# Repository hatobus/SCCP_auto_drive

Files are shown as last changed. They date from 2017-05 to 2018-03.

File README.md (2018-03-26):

# SCCP_auto_drive

I want to Shishi 



## 最初に

これは会津大学課題プロジェクト「自動車の自動運転」についてのレポジトリとなります．

### 使うもの

今回使用するものは主にamazonや秋月電子で購入できるものを軸に使用しています．

- モータードライバ DRV8830 
    秋月などで購入することができます．表面実装済みですのである程度使いやすいことが特徴です．I2Cで動かすのでそれなりに知識が必要ですが慣れてしまえば
    簡単に動かすことができます．二つ使用するのでどちらかのアドレスを変更する作業をする必要があります．
    [購入](http://akizukidenshi.com/catalog/g/gK-06489/)
    [データシート](http://akizukidenshi.com/download/ds/akizuki/AE-MOTOR8830_manual.pdf)
    
 - ~~測距モジュール HC-SR40
    Amazonで購入，超音波型です．安いのが特徴で6個程搭載しています．これはGPIOで動くのでI2Cよりは操作がしやすいと思います．~~
    [購入](http://amzn.asia/jd95G4C)
    [データシート](http://akizukidenshi.com/download/ds/sainsmar/hc-sr04_ultrasonic_module_user_guidejohn_b.pdf)
	
 - 測距モジュール LV-EZ1
 	HC-SR40を使用すると，精度が出ず，値がバラバラになる．そのため，同じ超音波を使って測距するLV-EZ1を使用した．PWM制御ができ，GPIOピンを一つしか使用しないのである程度は使いやすい．
	[購入](https://www.switch-science.com/catalog/139/)
	[データシート](http://maxbotix.com/documents/LV-MaxSonar-EZ_Datasheet.pdf)

 - ギアボックス ダブルギヤボックス 左右独立4速タイプ 
    amazonなどで購入することができます.左右独立なので小回りを利かせることができます．
    [購入](http://amzn.asia/8rwZjWK)
    
 - タイヤ 楽しい工作シリーズ（パーツ） No.111 スポーツタイヤセット （56mm径） [購入](http://www.tamiya.com/japan/products/70111/index.html)
 
 - ブレッドボード * 2
 - Raspberry pi 3
 - ジャンパケーブル
 
### 言語
  Python2系統，Raspberry piにデフォルトで入っているpythonのバージョンがpython2系統のためpython2での実装になります．
  Jupyter notebookというIPython notebookのフレームワークを用い，ssh接続などをせずブラウザ上でファイルを編集することができます．
  
  元はデータ処理のフレームワークだったこともあり，のちのディープラーニングのステップでの使用を見越した利用になります．

### Raspberry piのホスト名について
  ホスト名は，研究室で使っていて，固定IPにするとRaspberry piが死ぬことになるので，Raspberry piのホスト名をHatopiに変更．
  これにより，Bounjourを使用して，`ssh pi@Hatopi.local`でssh接続ができるようになる．
  これでIPが変更されても，sshで入ってIPを確認することができる．
  2017/11/09   Raspberry piのパスワードを変更

### 更新
2018 / 03/ 21 ... 使用するディープラーニングのライブラリをdarknetにするということで、ディレクトリ構造等を色々変更

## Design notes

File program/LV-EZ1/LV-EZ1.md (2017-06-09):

# LV-EZ1

今回のSCCPで使用しようとしていたHC-SR04は,誤差が大きく．実際に使用するとなると，誤差の分を考えなくてはいけない．

そのため当初予定していたHC-SR04を使わず，LV-EZ1を使用するということにした．

## Data sheets

データシートは[こちら](http://maxbotix.com/documents/LV-MaxSonar-EZ_Datasheet.pdf) LV-EZシリーズ共通のデータシートになっているので，他の製品のデータを見たりすることがないように注意．

入力はシリアル通信，アナログ，PWMでデータを取得できる．Arduinoの場合はアナログ入力を利用する．今回はRaspberry piで使用し，PWMを用いてデータを取得してくる．

## 配線
配線は以下の通り，今回はPWMのピンをGPIOで制御する．

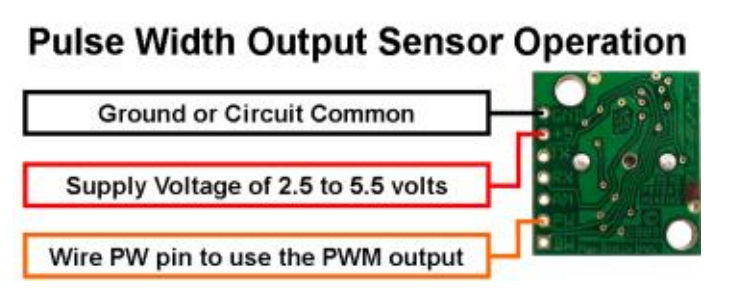
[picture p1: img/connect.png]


PWM制御なのでPWMの部分にピンを接続．

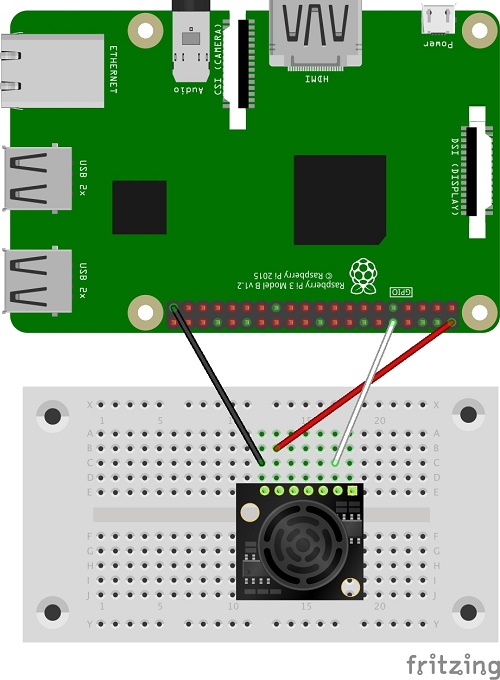
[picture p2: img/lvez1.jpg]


左から GND(-) VCC(+) 5.0V GPIO(ここではGPIO15) に接続する．
これで接続自体は完了する．あとはプログラムを走らせるのみ．

## プログラム

実際に行っていることとしては,前までに使用していたHC-SR04のプログラムとほぼ同じである．
GPIOのピンが一本だけになったが，これ一本でも制御が可能になる．
``` distance.py
import time
import RPi.GPIO as GPIO

# Use BCM GPIO references
# instead of physical pin numbers
GPIO.setmode(GPIO.BCM)

# Define GPIO to use on Pi
GPIO_TRIGECHO = 15

print "Ultrasonic Measurement"

# Set pins as output and input
GPIO.setup(GPIO_TRIGECHO,GPIO.OUT)  # Initial state as output

# Set trigger to False (Low)
GPIO.output(GPIO_TRIGECHO, False)

def measure():
  # This function measures a distance
  # Pulse the trigger/echo line to initiate a measurement
    GPIO.output(GPIO_TRIGECHO, True)
    time.sleep(0.00001)
    GPIO.output(GPIO_TRIGECHO, False)
  #ensure start time is set in case of very quick return
    start = time.time()

  # set line to input to check for start of echo response
    GPIO.setup(GPIO_TRIGECHO, GPIO.IN)
    while GPIO.input(GPIO_TRIGECHO)==0:
        start = time.time()

  # Wait for end of echo response
    while GPIO.input(GPIO_TRIGECHO)==1:
        stop = time.time()

    GPIO.setup(GPIO_TRIGECHO, GPIO.OUT)
    GPIO.output(GPIO_TRIGECHO, False)

    elapsed = stop-start
    distance = (elapsed * 34300)/2.0
    time.sleep(0.1)
    return distance

try:

    while True:
        distance = measure()
        print "  Distance : %.1f cm" % distance
        time.sleep(1)

except KeyboardInterrupt:
    print("Stop")
    GPIO.cleanup()
```

これを実行すると，一秒間隔で値を取得できる．HC-SR04と比べた結果，LV-EZ1のほうが信頼性が高いことが分かる．

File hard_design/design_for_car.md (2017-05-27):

# デザインについて

デザインはこちらに置いておく．

### シャシーの上側，下側，測距モジュール搭載用のアクリルのもの．

これは.aiファイルなので，Adobe Illustratorのみでしか開くことができない．

ちなみに，会津大学のGeek Dojoで，レーザーカッターを使用すれば，アクリル板の加工にて作成が可能．

アクリル板の厚さは3mm.大きさとしては45*60cmのものがあれば作成が可能，上下に微妙に差があるのでデザインなどで表裏を区別する必要がある．

### 3Dデザイン
これはギアボックスとタイヤを接続する部分のものである．

これを２つ出力すれば長さがちょうどよくなる．ギアボックスのギア比は 114.7 : 1
で作成しておく．

これもGeek Dojoで作成が可能だが，3Dプリンターで出力できればなんでも良い．

3Dプリンターで出力にかかる時間は約１時間程度．両方作るためには２時間程度が必要と見込まれる．

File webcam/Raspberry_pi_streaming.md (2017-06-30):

# Raspberry piでストリーミング

Raspberry piにWebカメストリーミング再生する方法．

### TODOリスト

- MJPG-streamerのインストール
- デーモン化（自動起動設定）

### まずはMJPG-streamerをインストールする．

参考にしたのは[こちら](http://www.hiramine.com/physicalcomputing/raspberrypi3/webcamstreaming.html)，ここに書かれているコードを一通り見ればインストールは可能．

メモ程度にコードを書き留めておく．

1. 最新のパッケージリストを取得．
	`sudo apt-get update`

2. MJPG-streamerに必要なパッケージをインストール
	`sudo apt-get install subversion libjpeg-dev imagemagick`

3. MJPG-streamerのソースファイルの取得とコンパイル（make）
	`svn co https://svn.code.sf.net/p/mjpg- streamer/code/mjpg-streamer mjpg-streamer`

	`cd mjpg-streamer`
	
	`make`
	
とりあえずこれでMJPG-Streamerが起動するようになる．
起動のためのコマンドは．
`sudo ./mjpg_streamer -i "./input_uvc.so -f 10 -r 320x240 -d /dev/video0 -y -n" -o "./output_http.so -w ./www -p 8080"`

となる．あとは同一LAN上にいるPCのブラウザで．


`Rasppi's IP:8080`
を入力することで，ストリーミング画面が見ることができる．

## 自動起動設定

このままだと，いつもターミナル上からコマンドを叩かなくてはいけず，起動させるのが面倒になる．そのため自動起動のためのスクリプトを作成する．

1. Raspberry pi上の`home/`に`tool`などのフォルダを作成する．

2. `tool`フォルダ内に`stream.sh`を置く．これで起動時に実行されるシェルを作成できる．

3. アクセス権を変更．

	`chmod 700 stream.sh`

4. スクリプトをデーモン化
	※デーモンは，LinuxやUNIXにおいてメモリ上に常駐して様々なサービスを提供するプロセスを指す。
	
	Supervisorによってスクリプトをデーモン化する。

	そのためにまずは、Supervisorのインストール

	`sudo apt-get update`
	`sudo apt-get install supervisor`

5. 設定ファイルを次のコマンドで作成。

	`sudo vim /etc/supervisor/conf.d/mjpg_streamer_boot.conf
`
	内容としては以下の通り
	```mjpg_streamer_boot.conf
	[program:mjpg_streamer_boot]
	command=/home/pi/tool/stream.sh
	user=root
	autostart=true
	redirect_stderr=true
	stdout_logfile=/var/log/supervisor/mjpg_streamer_boot.log
	stdout_logfile_maxbytes=1MB
	stdout_logfile_backups=1
	stdout_capture_maxbytes=1MB
	```
	
6. ひとまずこれで自動起動の設定は完了．
	
	`sudo reboot`

	コマンドでRaspberry piを再起動できるので再起動し，実際にMJPG-Streamserが起動しているかを確認する．
	
	ちなみに，MJPG-StreamerはスマホでもPCでも閲覧が可能である．

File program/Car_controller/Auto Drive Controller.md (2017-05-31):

# Auto Drive Controller
自動走行車が動くようになったが，これからは学習をさせていかなければならない，そのためには学習をさせなければいけない．

その時に必要なのが人間の手による走行，ラジコンを走行させ，実際にデータを取得するのが目標．距離のデータをまずは取りたいのでデータセットを作る必要がある．

jupyter notebook上から制御ができるようになるためには，jupyter notebook上でGUIを動かさなければいけない．

当初はRaspberry pi側からTkinterなどを使用したプログラムでGUI画面をjupyter notebook上に持ってこようと思ったが，デフォルトではssh接続をしながらGUIを持ってくることができなかった．そのためTkinterを使用してラジコンのコントローラーを作成できなかった．

そのため使用したのが [こちら](https://blog.dominodatalab.com/interactive-dashboards-in-jupyter/)のサイト，どうやらjupyter notebook上でHTMLなどを利用したGUIを作成できるそう．

GitHub : https://github.com/jupyter-widgets/ipywidgets

## 実装

Readme.ipynbにて詳細を書く．

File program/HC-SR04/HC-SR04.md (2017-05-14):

# HC-SR04について

ここではこのラジコンカーに搭載されている測距モジュール，HC-SR04について書いています．

### 概要
HC-SR04は超音波を用いた測距モジュールで超音波の往復時間から対象物までの距離を算出するモジュールです．40kHzの周波数の超音波を出して、それが反射して戻って来るまでの時間から距離を計測するセンサーです。

### データ
[データシート](http://akizukidenshi.com/download/ds/sainsmar/hc-sr04_ultrasonic_module_user_guidejohn_b.pdf)

|　電気的パラメータ　|　データ　|
|:--:|:--:|
|電源入力| 5.0V |
|操作電流|15mA|
|周波数| 40kHz |
|最長測定距離| 400cm(4.0m) |
|最短測定距離| 2.0cm |
|検査角度| 15$^\circ$ |
|シグナル入力時間|10us以上|

データシートから一部抜粋．

#### 測距方法
左がら2番目の「Trig」というのがトリガー（Trigger）である。ここにパルス的に電圧を掛ける．（時間は10μ秒以上）すると2つのスピーカーから40kHzという超音波が8回放たれる。
放出した超音波は対象物に当たりセンサー側に戻り，戻ってきたら、右から2番目の「Echo」というピンにそのかかった時間分電圧が出力される（HIGH状態）．よって，EchoがHIGHになっている時間と音波が空気中を伝わる速さから，その距離が計算できる．

### 距離の計算
戻り値のパルス時間（μ秒単位）から距離を計算する.まず音は1秒間で空気中をおよそ340mで伝わる．この速度は温度など周りの環境で随分と変わってしまう.例えば15度ほどだと340mだが，30度だと349mと9mも変わってししまう．より正確に距離を計測するには，温度をファクターとして入れた方が良い，精度を持たせる際には別の温度モジュールなどを設置し，リアルタイムで温度を取得，適宜音速を算出し計算する．という方法を取るのが最善だと思われる．

### 計算式
計算自体は簡単なものである．
超音波が放出され，反射して戻って来る時間を$t \mu s$とする．1秒($= 1000000 \mu s$)で340m伝わるので．$t\mu s$だと$$\frac{340 m \times t}{1000000}$$で往復の距離(m),その半分で反射したものまでの距離が算出できる．もしこれをcmに直す際には.
$$\frac{340 \times t}{1000000 \times 100} = \frac{340 \times t}{1000} \times \frac{1}{2} = 0.017 \times t$$

この計算式で目標までの距離がcmで算出できる．

### 注意
#### 検査角度について
このモジュールの検査角度は15$^\circ$であり，測定値の誤差がある時がある，最大の4mの時には測定する対象がそのモジュールの直線上から10.826cm右左にずれる．複雑な地形の場合，このようなモジュールよりも精度の高いものを使用したほうがいいと言える．



この画像は4.0mの場合の検査角度についての画像である．
左のモジュールから放出された超音波は右の壁までの間を往復する．その際測定誤差は15$^\circ$であるので，距離が測定される範囲は緑色の線を２倍した距離と等しくなる．

ここで緑の部分の長さを求める．この直角三角形の角度は7.5$\circ$．この三角形の高さ$h$を求めるためには，以下の式を解けば良い．

\begin{eqnarray}
  tan7.5 = \frac{4}{h} \\
\end{eqnarray}

これを解くと，以下のようになる．

\begin{eqnarray}
  tan7.5 = \frac{4}{h} \\
  h = 4 \times tan7.5 \\
  h \approx 10.824
\end{eqnarray}
つまり，これを2倍するので，21.648cmの幅で距離が計測されることに気をつけたい．

github上ではmarkdownに書かれた数式が反映されないようなので数式がどのようなものであるか
確認したい際は [こちら](https://hackmd.io/s/HJyQI3VlW) をご覧ください．

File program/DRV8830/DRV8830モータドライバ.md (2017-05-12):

# DRV8830モータドライバ

今回の自動操縦カーに搭載されているのは左右独立型のギアボックス．つまり，左右の動きを別々に制御できるというものです．そのため小回りを効かせることができ．サーボの分も減らすことができるので自動走行のプログラムも簡素に書くことが可能になります．

### データシート

- DRV8830自体のものは　　[こちら](https://strawberry-linux.com/pub/drv8830j.pdf)
- 今回ラジコンカーに乗っている表面実装などが住んでいるものは [こちら](http://akizukidenshi.com/download/ds/akizuki/AE-MOTOR8830_manual.pdf)

### 接続方法

このICはGPIOではなくI2Cデバイスになっているので，最初にRaspberry pi側でI2Cを有効にしなければいけません．そのためにはまずはterminalから `sudo raspi-config` でRaspberry piのセッティング画面に入り， `5-Interfacing Option` の I2Cを有効化する必要があります．

また，このモータドライバのアドレスはデフォルトで 0x64 に設定されています．しかし，今回は２つラジコンカーに乗せているので，アドレスを変更しなければいけません．アドレスが一緒のままでいると，二つが連動して動くことになるので．アドレスの変更は必須になります．

データシートによると，配線でアドレスを変更できるとなっていますが，今回はハンダを用いてアドレスを変更しました．ちなみにアドレスはこのままではなく，1ビット右にシフトした値がアドレスになります．



今回は 0x62 に変更をしたので A0 ピンの上側にハンダを付け A1 ピンの下側にハンダをつけました．この理論でいけば9通りまでのアドレスの変更が可能です．

そして配線をし，terminal上で確認するとこのようになるはずだと思われます．

    $ sudo i2cdetect -y 1
    
    0  1  2  3  4  5  6  7  8  9  a  b  c  d  e  f
    00:          -- -- -- -- -- -- -- -- -- -- -- -- -- 
    10: -- -- -- -- -- -- -- -- -- -- -- -- -- -- -- -- 
    20: -- -- -- -- -- -- -- -- -- -- -- -- -- -- -- -- 
    30: -- -- -- -- -- -- -- -- -- -- -- -- -- -- -- -- 
    40: -- -- -- -- -- -- -- -- -- -- -- -- -- -- -- -- 
    50: -- -- -- -- -- -- -- -- -- -- -- -- -- -- -- -- 
    60: -- -- 62 -- 64 -- -- -- -- -- -- -- -- -- -- -- 
    70: -- -- -- -- -- -- -- --                         

こうなればRaspberry pi上で二つのモータードライバが認識されていることになっています．

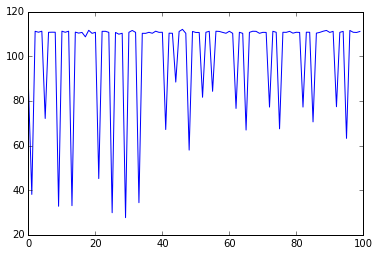
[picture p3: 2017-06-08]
img/HCSR04.png

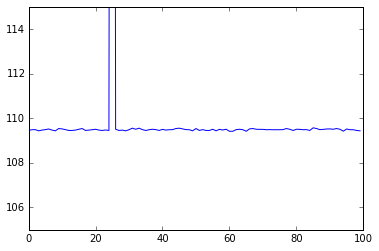
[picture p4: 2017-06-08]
img/lvez.png

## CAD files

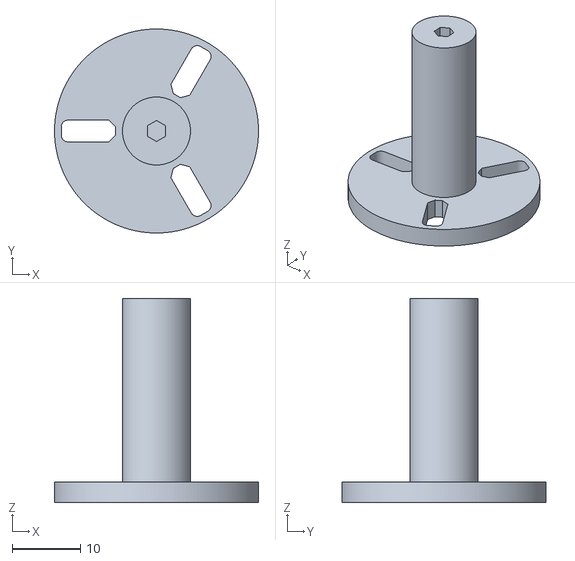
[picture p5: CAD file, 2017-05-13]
hard_design/sussystem.stl
30.0 x 30.0 x 30.0

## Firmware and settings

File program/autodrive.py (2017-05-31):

# -*- coding: utf-8 -*- 
import smbus
import time
import RPi.GPIO as GPIO
import sys


## DRV8830 Default I2C slave address
Right_ADDRESS = 0x62 # right moter
Left_ADDRESS = 0x64 # left moter

''' DRV8830 Register Addresses '''
## sample rate driver
CONTROL = 0x00

## Value motor.
FORWARD = 0x01
BACK = 0x02
STOP = 0x00

## smbus
bus = smbus.SMBus(1)

class Car():   
    flg = True

    def ard_map(self, x, in_min, in_max, out_min, out_max):
        return (x - in_min) * (out_max - out_min) // (in_max - in_min) + out_min
    #mapで1-100のスケールを1-58までに対応させている．(言うなればAからBへ一対一対応)

    def __init__(self):
        pass
    
    ########################################
    #                                                                  #
    #                     Right side Motor                         #
    #                                                                  #
    ########################################
          
    # speedは1-100で指定
    def R_forward(self, speed):

        self.direction = FORWARD
        s = self.ard_map(speed, 1, 100, 1, 58)
        sval = FORWARD | ((s+5)<<2) #スピードを設定して送信するデータを1Byte作成
        bus.write_i2c_block_data(Right_ADDRESS,CONTROL,[sval]) #生成したデータを送信

    def R_stop(self):
        bus.write_i2c_block_data(Right_ADDRESS,CONTROL,[STOP]) #モータへの電力の供給を停止(惰性で動き続ける)
        
    # speedは0-100で指定
    def R_back(self, speed):
        
        self.direction = BACK
        s= self.ard_map(speed, 1, 100, 1, 58)
        sval = BACK | ((s+5)<<2) #スピードを設定して送信するデータを1Byte作成
        bus.write_i2c_block_data(Right_ADDRESS,CONTROL,[sval]) #生成したデータを送信

    def R_brake(self):
        bus.write_i2c_block_data(Right_ADDRESS,CONTROL,[0x03]) #モータをブレーキさせる
        
    
    ########################################
    #                                                                  #
    #                      Left side Motor                          #
    #                                                                  #
    ########################################
    
    # speedは1-100で指定
    def L_forward(self, speed):

        self.direction = FORWARD
        s = self.ard_map(speed, 1, 100, 1, 58)
        sval = FORWARD | ((s+5)<<2) #スピードを設定して送信するデータを1Byte作成
        bus.write_i2c_block_data(Left_ADDRESS,CONTROL,[sval]) #生成したデータを送信

    def L_stop(self):
        bus.write_i2c_block_data(Left_ADDRESS,CONTROL,[STOP]) #モータへの電力の供給を停止(惰性で動き続ける)
        
    # speedは0-100で指定
    def L_back(self, speed):
        if speed < 0:
            raise ValueError("value is under 1,  must define 1-100 as speed.")
        elif speed > 100:
            raise ValueError("value is over 100,  must define 1-100 as speed.")

        self.direction = BACK
        s= self.ard_map(speed, 1, 100, 1, 58)
        sval = BACK | ((s+5)<<2) #スピードを設定して送信するデータを1Byte作成
        bus.write_i2c_block_data(Left_ADDRESS,CONTROL,[sval]) #生成したデータを送信

    def L_brake(self):
        bus.write_i2c_block_data(Left_ADDRESS,CONTROL,[0x03]) #モータをブレーキさせる
        
     ########################################
    #                                                                  #
    #                      Both side Motor                         #
    #                                                                  #
    ########################################

    #前進
    # speedは1-100で指定
    def forward(self, speed):

        self.direction = FORWARD
        s = self.ard_map(speed, 1, 100, 1, 58)
        sval = FORWARD | ((s+5)<<2) #スピードを設定して送信するデータを1Byte作成
        bus.write_i2c_block_data(Left_ADDRESS,CONTROL,[sval]) #生成したデータを送信
        bus.write_i2c_block_data(Right_ADDRESS,CONTROL,[sval])
    #停止(ブレーキはかけない)
    def stop(self):
        bus.write_i2c_block_data(Left_ADDRESS,CONTROL,[STOP]) #モータへの電力の供給を停止(惰性で動き続ける)
        bus.write_i2c_block_data(Right_ADDRESS,CONTROL,[STOP])
    #後進
    # speedは0-100で指定
    def back(self, speed):
        if speed < 0:
            raise ValueError("value is under 1,  must define 1-100 as speed.")
        elif speed > 100:
            raise ValueError("value is over 100,  must define 1-100 as speed.")

        self.direction = BACK
        s= self.ard_map(speed, 1, 100, 1, 58)
        sval = BACK | ((s+5)<<2) #スピードを設定して送信するデータを1Byte作成
        bus.write_i2c_block_data(Left_ADDRESS,CONTROL,[sval]) #生成したデータを送信
        bus.write_i2c_block_data(Right_ADDRESS,CONTROL,[sval])
    
    #ブレーキ
    def brake(self):
        bus.write_i2c_block_data(Left_ADDRESS,CONTROL,[0x03]) #モータをブレーキさせる
        bus.write_i2c_block_data(Right_ADDRESS,CONTROL,[0x03])
    
    #左回転
    #speed -100から100までスピードを変化
    #pitch 1から10まで曲がる角度を変化
    def left(self,speed,pitch):
        if speed < -100:
            raise ValueError("value is under -100,  must define -100~100 as speed.")
        elif speed > 100:
            raise ValueError("value is over 100,  must define -100~100 as speed.")
        
        if pitch < 1:
            raise ValueError("value is under 1,  must define 1-10 as pitch.")
        elif pitch > 10:
            raise ValueError("value is over 10,  must define 1-10 as pitch.")
        
        #斜め後ろに移動
        if speed <0:
            tforward = BACK
            tback = FORWARD
            speed *= -1
        #停止
        elif speed == 0:
            bus.write_i2c_block_data(Right_ADDRESS,CONTROL,[STOP]) #生成したデータを送信
            bus.write_i2c_block_data(Left_ADDRESS,CONTROL,[STOP])
            return
        #斜め前に移動
        else:
            tforward = FORWARD
            tback = BACK
        
        self.direction = tforward
        
        s = self.ard_map(speed*(5-pitch)/5, 1, 100, 1, 58)
        #s -= (pitch) * (58/5)
        if s > 0:
            sval = tforward | ((s+5)<<2) #スピードを設定して送信するデータを1Byte作成
        elif s == 0:
            sval = STOP #スピードを設定して送信するデータを1Byte作成
        else:
            sval = tback | ((-s+5)<<2) #スピードを設定して送信するデータを1Byte作成
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

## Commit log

2017-05-10 IPython Notebookってなに？
    説明書として
2017-05-13 3D design
    [sussystem.stl]
2017-05-27 update design
    [sussystem.stl]
2017-06-08 add compare HC-SR04 LV-EZ1 sensors file
2017-06-16 add csv and csvplot file
    [distdata.csv]
2017-06-28 threading and gather distdata
2017-06-29 新しいグラフ作成のもの，今までのものはデータが大きいとどうもうまく読み込みができない
2017-07-20 update dataset
    [distdata000.csv]
2017-10-26 Raspberry piのホスト名について変更
2017-10-26 データをcsvに書き出すところを変更
2017-11-02 create dataset/pic
    [distdata.csv, distdata000.csv]
2017-11-09 ダブっているファイルがあったので消去
2017-12-28 To attach flake8
2018-03-21 いらないファイルを消去
2018-03-21 [Update] ファイル形式を大幅に変更。これから大雑把にクラス分けをしていく
    [distdata.csv, distdata000.csv]
2018-03-21 [update] いらないファイルを消した
2018-03-26 darknet用に画像を移動させた
2018-03-26 [update] 画像ファイルを移動
2018-04-05 [update] To attach bounding box
2018-04-06 [Update] To attach bounding box for yield
2018-04-09 [Update] 進入禁止の標識にバウンディングボックスを設置
2018-04-10 [Update] バウンディングボックスを作っていないファイルを消した
2018-04-13 Revert "[Update] バウンディングボックスを作っていないファイルを消した"
    This reverts commit 48813f338c55f6e49e31213a0e38d78360f9e7a7.
2018-04-14 [Update] 画像ファイル一覧を出力するファイルを追加

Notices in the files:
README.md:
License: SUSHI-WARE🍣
